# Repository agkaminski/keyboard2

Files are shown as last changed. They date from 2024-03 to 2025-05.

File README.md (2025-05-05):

# keyboard2

This repository contains designs of mechanical keyboards. Purpose of these
keyboards are custom DIY computers that are of all-in-keyboard design.

## keyboard69

This is a DIY 69% (nice) mechanical keyboard. Mostly to be used for DIY
computers, but there's a provision for USB/PS2 connection too.

Keyboard has been tested in the [FellaPC](https://github.com/agkaminski/FellaPC)
project and proven 100% functional. USB/PS2 connection has not been tested yet.

### Photos

#### Top



#### Bottom



## keyboard_mini

This is a reduced version of keyboard69 - rightmost column has been removed,
PCB size is as small, as possible. Provision for USB/PS2 has been removed.
Other connectors remain compatible with keyboard69.

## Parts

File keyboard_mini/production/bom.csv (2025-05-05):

Designator | Footprint | Quantity | Value | LCSC Part #
C1, C2 | 0805 | 2 | 100n
D1, D10, D11, D12, D13, D14, D16, D17, D18, D19, D2, D20, D21, D22, D23, D24, D25, D26, D27, D28, D29, D3, D31, D32, D33, D34, D35, D36, D37, D38, D39, D4, D40, D41, D42, D43, D45, D46, D47, D48, D49, D5, D50, D51, D52, D53, D54, D55, D56, D57, D59, D6, D60, D61, D62, D63, D64, D65, D66, D67, D7, D8, D9 | D_MiniMELF | 63 | D
J1 | IDC-Header_2x06_P2.54mm_Vertical | 1 | Conn_02x06_Odd_Even
J2 | PinSocket_1x12_P2.54mm_Vertical | 1 | Conn_01x12
J3 | TE_1-84952-2_1x12-1MP_P1.0mm_Horizontal | 1 | Conn_01x12_MountingPin
R10, R11, R12, R6, R8, R9 | 0805 | 6 | 10K
R7 | 0805 | 1 | DNP
SW1, SW10, SW11, SW12, SW13, SW17, SW18, SW19, SW2, SW20, SW21, SW22, SW23, SW24, SW25, SW26, SW27, SW28, SW3, SW32, SW33, SW34, SW35, SW36, SW37, SW38, SW39, SW4, SW40, SW41, SW42, SW46, SW47, SW48, SW49, SW5, SW50, SW51, SW52, SW53, SW54, SW55, SW57, SW6, SW63, SW64, SW65, SW66, SW67, SW7, SW8, SW9 | SW_Cherry_MX_1.00u_PCB | 52 | SW_Push
SW14 | SW_Cherry_MX_2.00u_PCB | 1 | SW_Push
SW16, SW29 | SW_Cherry_MX_1.50u_PCB | 2 | SW_Push
SW31, SW56 | SW_Cherry_MX_1.75u_PCB | 2 | SW_Push
SW43, SW45 | SW_Cherry_MX_2.25u_PCB | 2 | SW_Push
SW59, SW60, SW61 | SW_Cherry_MX_1.25u_PCB | 3 | SW_Push
SW62 | SW_Cherry_MX_6.25u_PCB | 1 | SW_Push
U1, U2 | SOIC-16_3.9x9.9mm_P1.27mm | 2 | 74HC138

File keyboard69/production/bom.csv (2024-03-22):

Designator | Footprint | Quantity | Value | LCSC Part #
C1, C2, C4, C7 | 0805 | 4 | 100n
C3 | 0805 | 1 | 1u
C5, C6 | 0805 | 2 | 22p
D1, D10, D11, D12, D13, D14, D15, D16, D17, D18, D19, D2, D20, D21, D22, D23, D24, D25, D26, D27, D28, D29, D3, D30, D31, D32, D33, D34, D35, D36, D37, D38, D39, D4, D40, D41, D42, D43, D44, D45, D46, D47, D48, D49, D5, D50, D51, D52, D53, D54, D55, D56, D57, D58, D59, D6, D60, D61, D62, D63, D64, D65, D66, D67, D68, D7, D8, D9 | D_MiniMELF | 68 | D
J1 | IDC-Header_2x06_P2.54mm_Vertical | 1 | Conn_02x06_Odd_Even
J2 | PinSocket_1x12_P2.54mm_Vertical | 1 | Conn_01x12
J3 | TE_1-84952-2_1x12-1MP_P1.0mm_Horizontal | 1 | Conn_01x12_MountingPin
J4 | USB_Mini-B_Wuerth_65100516121_Horizontal | 1 | USB_B_Mini
J5 | PinHeader_2x03_P2.54mm_Vertical | 1 | Conn_02x03_Odd_Even
R1, R2, R3, R4, R5, R6 | 0805 | 6 | 10K
R10 | 0805 | 1 | 4K7
R11, R12 | 0805 | 2 | 22R
R7 | 0805 | 1 | DNP
SW1, SW10, SW11, SW12, SW13, SW15, SW17, SW18, SW19, SW2, SW20, SW21, SW22, SW23, SW24, SW25, SW26, SW27, SW28, SW3, SW30, SW32, SW33, SW34, SW35, SW36, SW37, SW38, SW39, SW4, SW40, SW41, SW42, SW44, SW46, SW47, SW48, SW49, SW5, SW50, SW51, SW52, SW53, SW54, SW55, SW57, SW58, SW6, SW63, SW64, SW65, SW66, SW67, SW68, SW7, SW8, SW9 | SW_Cherry_MX_1.00u_PCB | 57 | SW_Push
SW14 | SW_Cherry_MX_2.00u_PCB | 1 | SW_Push
SW16, SW29 | SW_Cherry_MX_1.50u_PCB | 2 | SW_Push
SW31, SW56 | SW_Cherry_MX_1.75u_PCB | 2 | SW_Push
SW43, SW45 | SW_Cherry_MX_2.25u_PCB | 2 | SW_Push
SW59, SW60, SW61 | SW_Cherry_MX_1.25u_PCB | 3 | SW_Push
SW62 | SW_Cherry_MX_6.25u_PCB | 1 | SW_Push
U1, U2 | SOIC-16_3.9x9.9mm_P1.27mm | 2 | 74HC138
U3 | TQFP-44_10x10mm_P0.8mm | 1 | ATmega16U4-A
Y1 | Crystal_HC49-4H_Vertical | 1 | Crystal

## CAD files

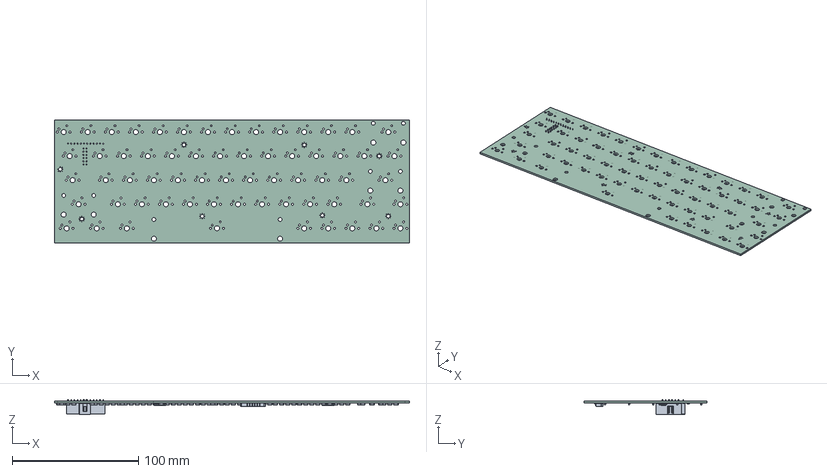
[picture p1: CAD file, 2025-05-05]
keyboard_mini/keyboard2.step
281.2 x 97.0 x 12.2 mm
D_MiniMELF x 63
PinSocket_1x12_P2.54mm_Vertical
R_0805_2012Metric x 7
SOIC-16_3.9x9.9mm_P1.27mm x 2
IDC-Header_2x06_P2.54mm_Vertical
C_0805_2012Metric x 2
TE_1-84952-2_1x12-1MP_P1.0mm_Horizontal
keyboard2_PCB

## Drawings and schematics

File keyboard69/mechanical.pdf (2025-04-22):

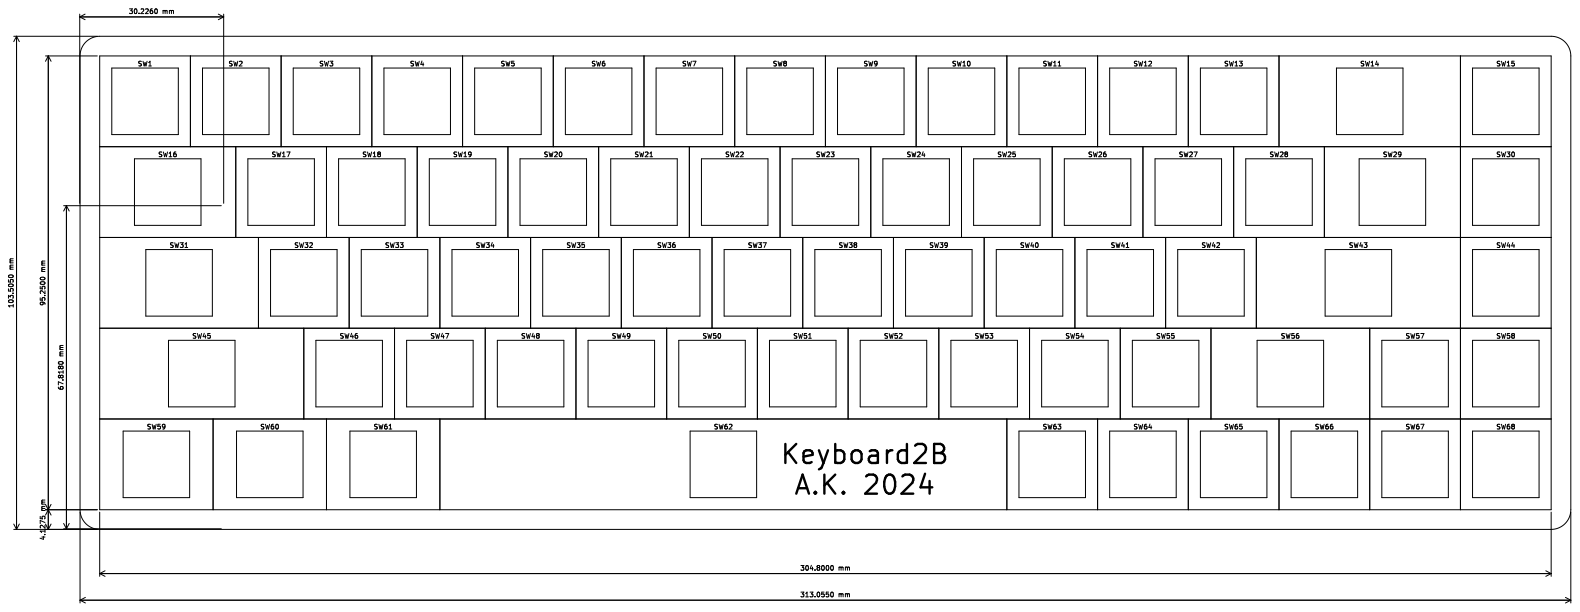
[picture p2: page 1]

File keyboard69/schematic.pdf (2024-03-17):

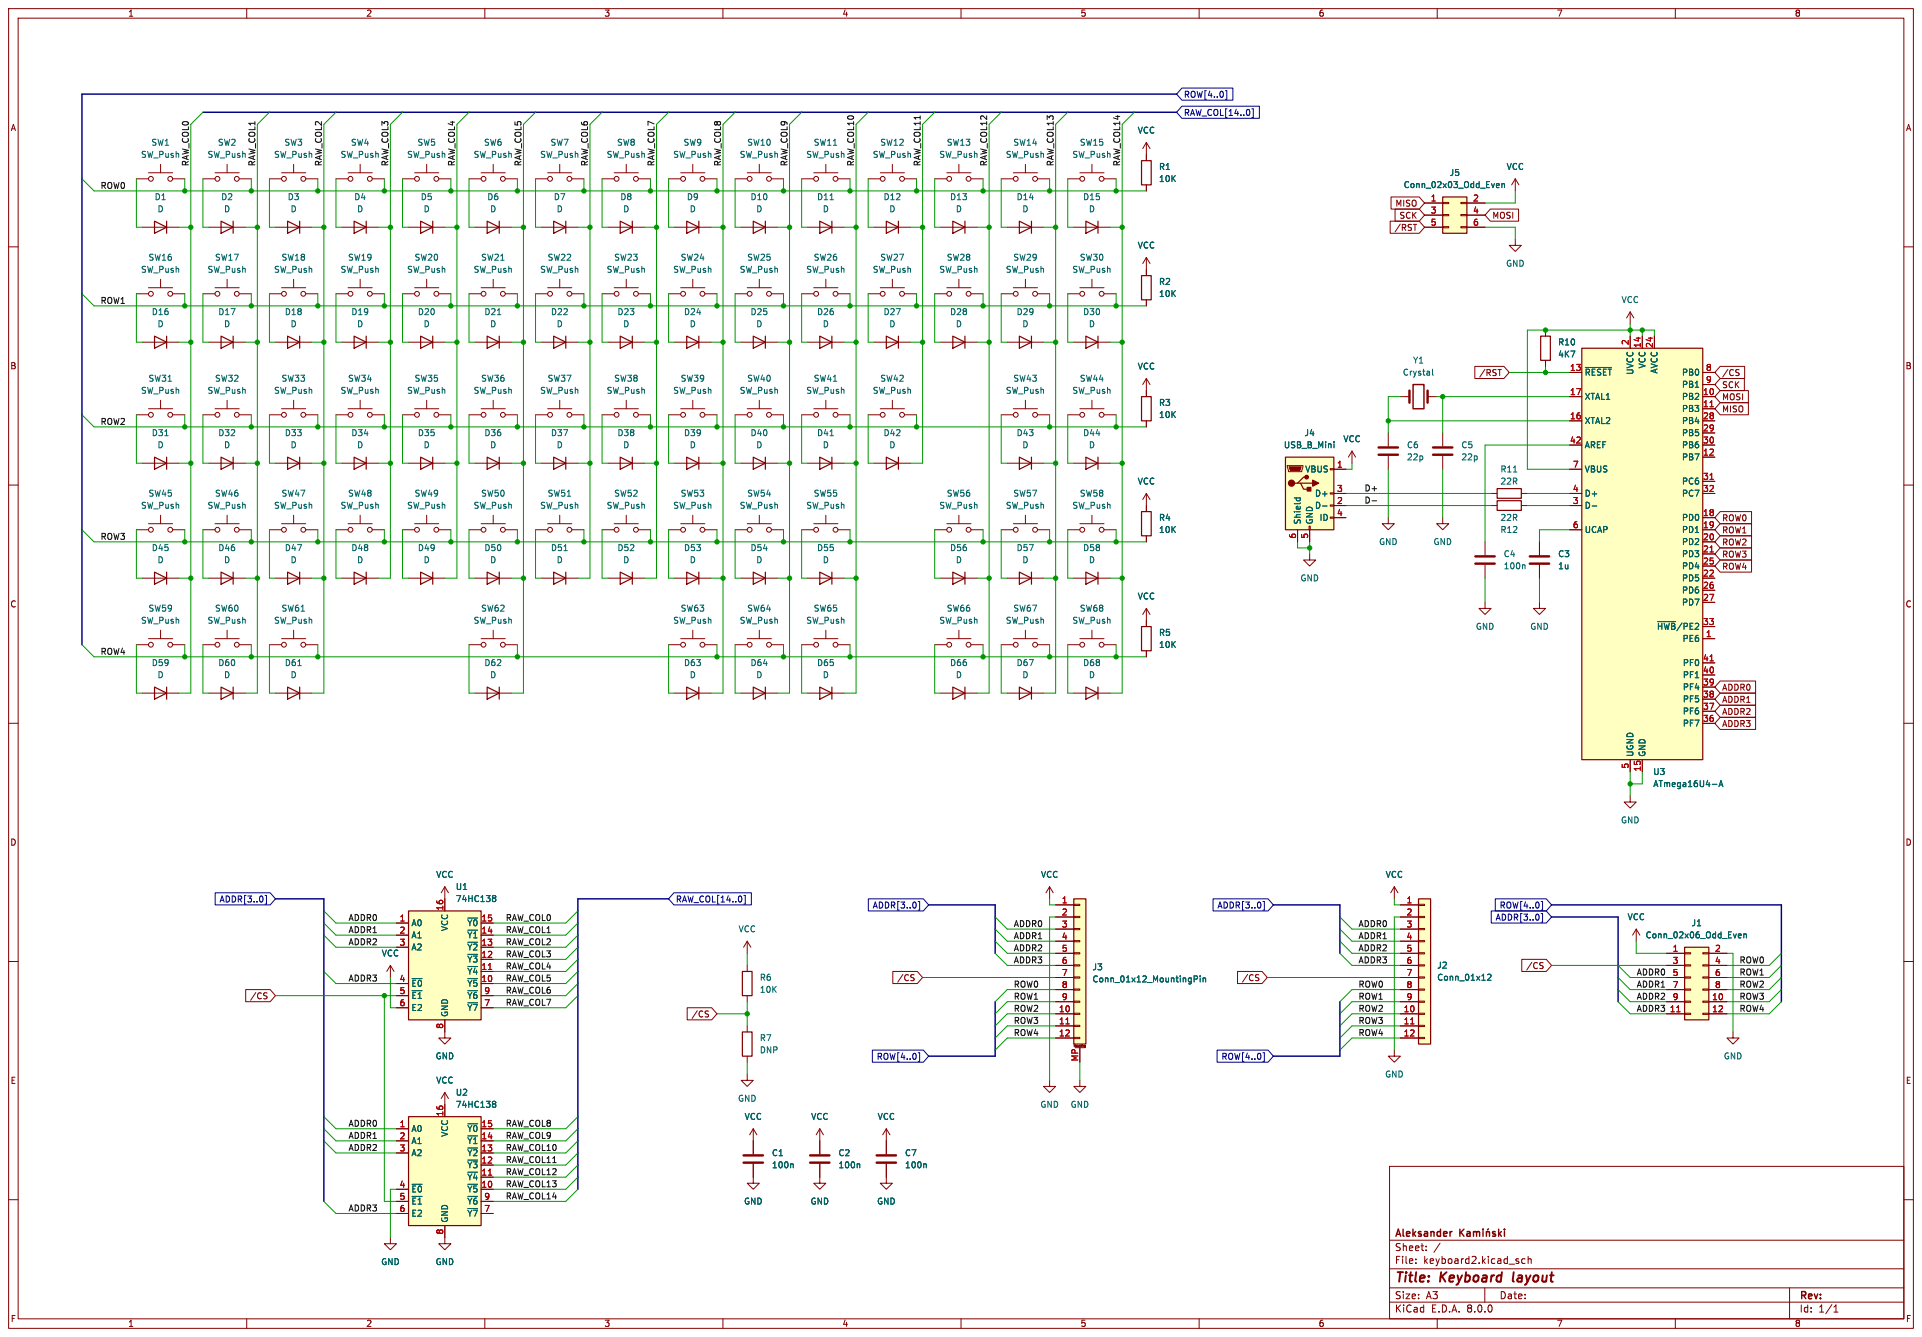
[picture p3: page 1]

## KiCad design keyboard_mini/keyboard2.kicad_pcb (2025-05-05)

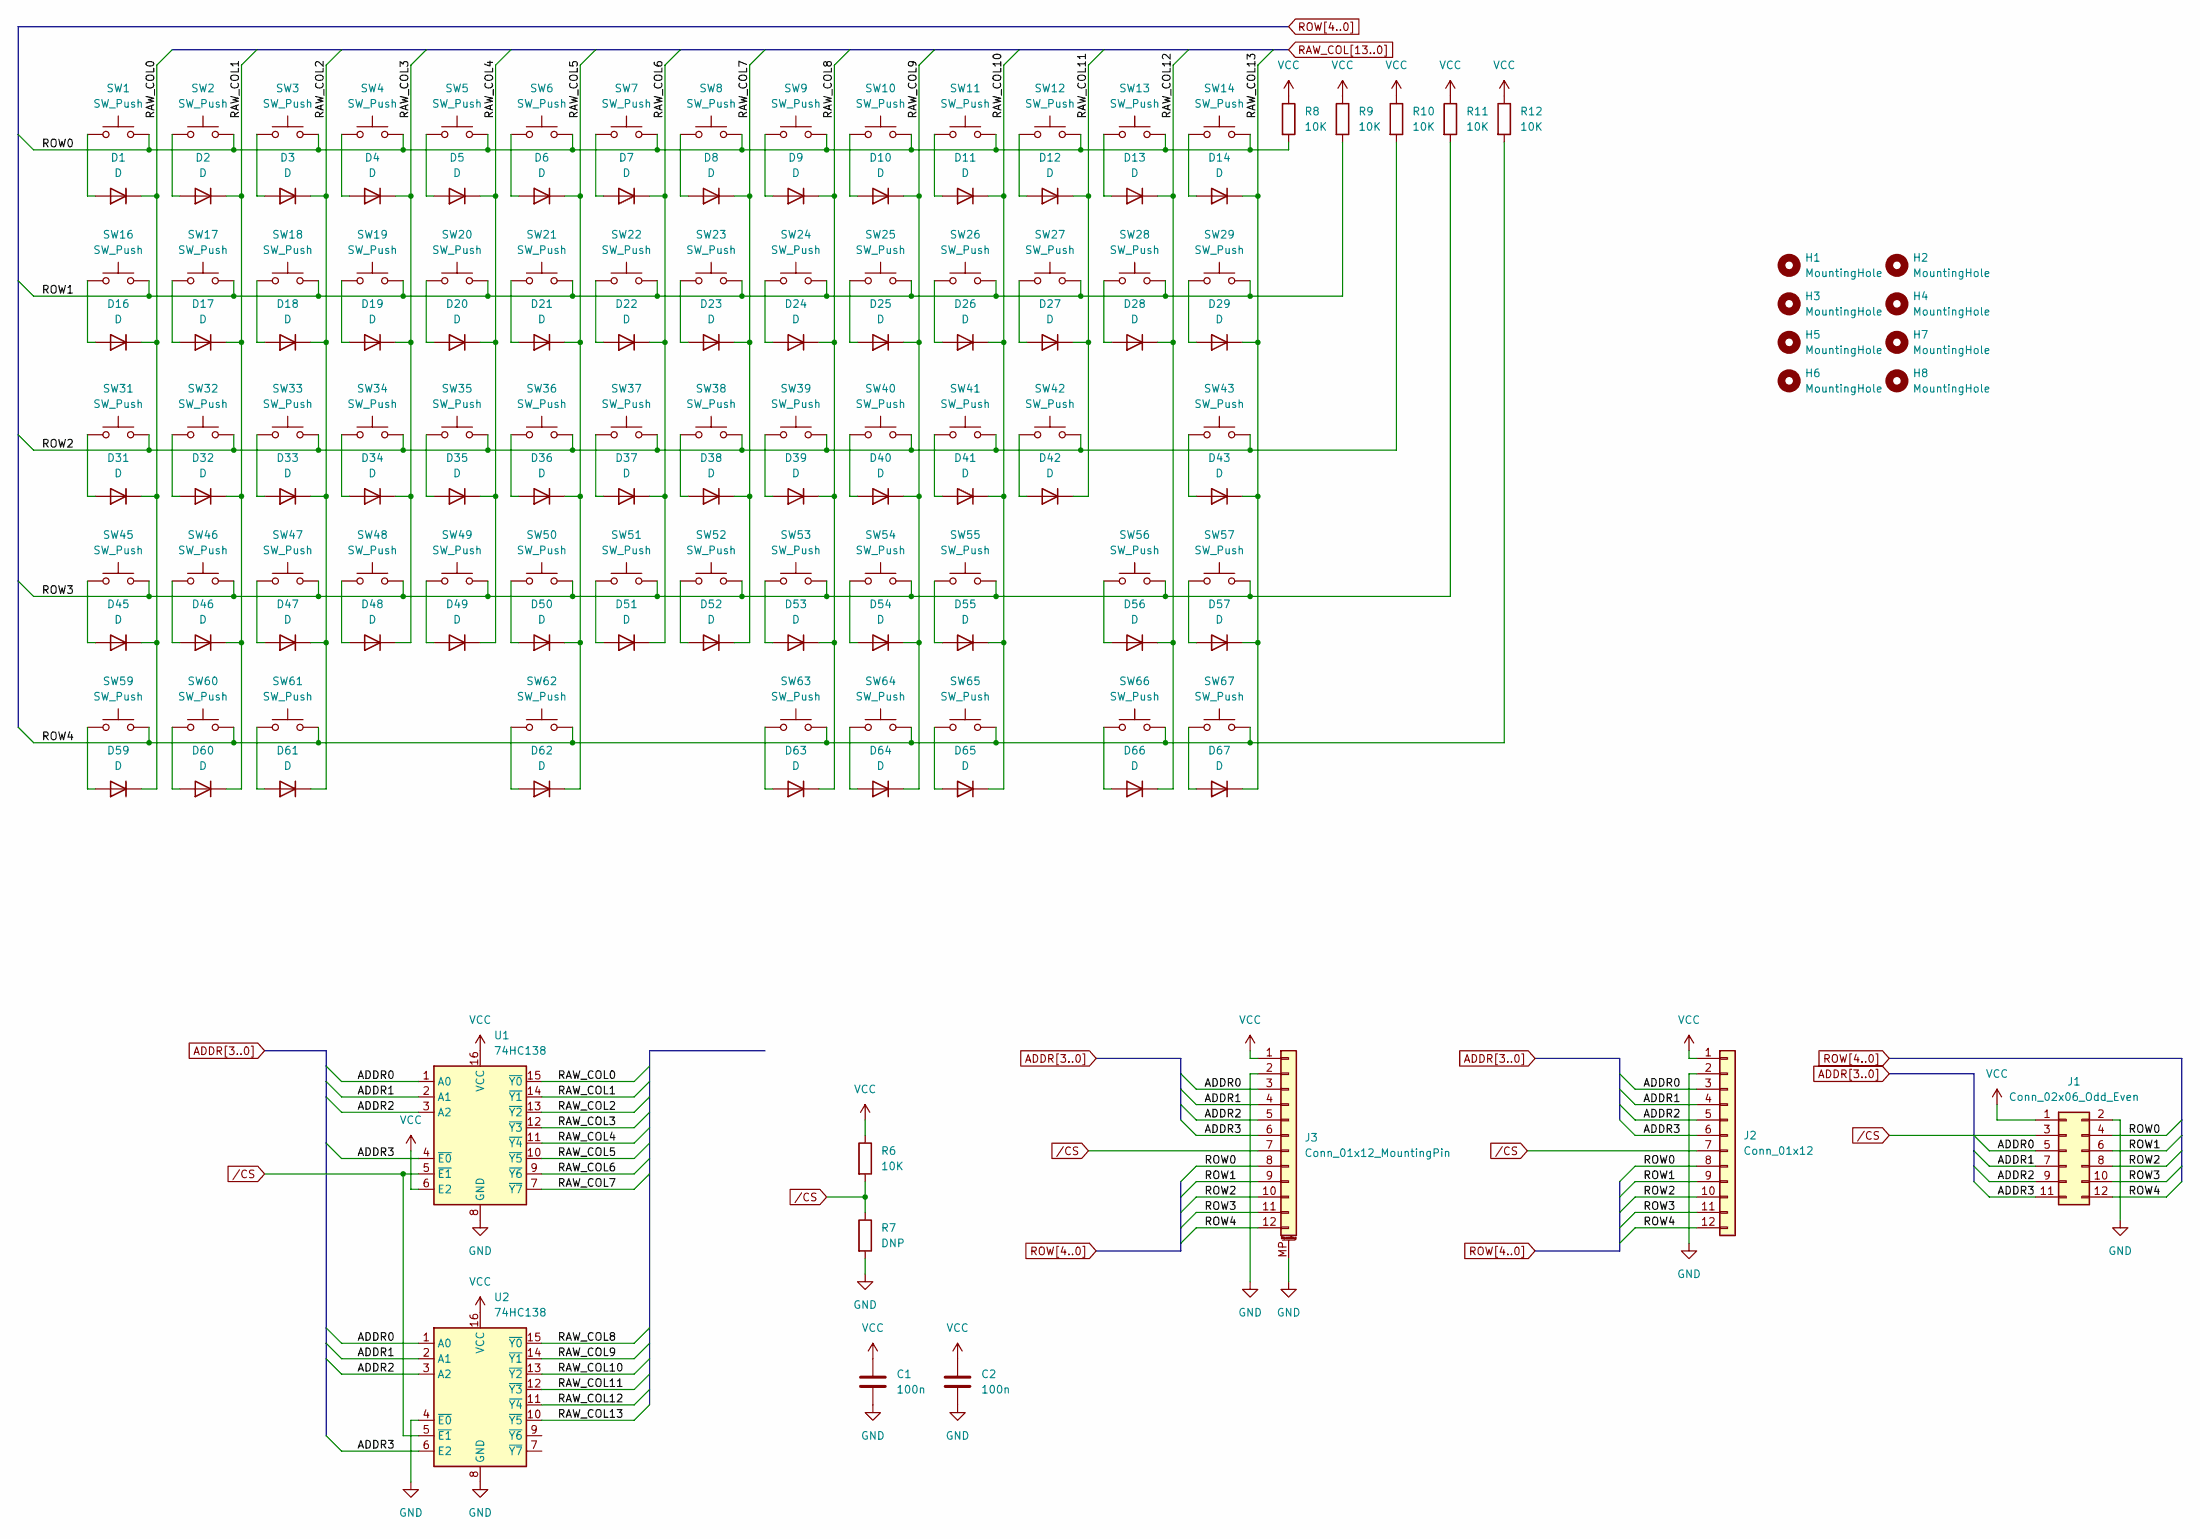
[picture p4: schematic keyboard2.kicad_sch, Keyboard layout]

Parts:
C1, C2: 100n; C_0805_2012Metric_Pad1.18x1.45mm_HandSolder
D1, D2, D3, D4, D5, D6, D7, D8, D9, D10, D11, D12, D13, D14, D16, D17, D18, D19, D20, D21, D22, D23, D24, D25, D26, D27, D28, D29, D31, D32, D33, D34, D35, D36, D37, D38, D39, D40, D41, D42, D43, D45, D46, D47, D48, D49, D50, D51, D52, D53, D54, D55, D56, D57, D59, D60, D61, D62, D63, D64, D65, D66, D67: D; D_MiniMELF
H1, H2, H3, H4, H5, H6, H7, H8: MountingHole; MountingHole_2.7mm_M2.5_Pad_Via
J1: Conn_02x06_Odd_Even; IDC-Header_2x06_P2.54mm_Vertical
J2: Conn_01x12; PinSocket_1x12_P2.54mm_Vertical
J3: Conn_01x12_MountingPin; TE_1-84952-2_1x12-1MP_P1.0mm_Horizontal
R6, R8, R9, R10, R11, R12: 10K; R_0805_2012Metric_Pad1.20x1.40mm_HandSolder
R7: DNP; R_0805_2012Metric_Pad1.20x1.40mm_HandSolder
SW1, SW2, SW3, SW4, SW5, SW6, SW7, SW8, SW9, SW10, SW11, SW12, SW13, SW17, SW18, SW19, SW20, SW21, SW22, SW23, SW24, SW25, SW26, SW27, SW28, SW32, SW33, SW34, SW35, SW36, SW37, SW38, SW39, SW40, SW41, SW42, SW46, SW47, SW48, SW49, SW50, SW51, SW52, SW53, SW54, SW55, SW57, SW63, SW64, SW65, SW66, SW67: SW_Push; SW_Cherry_MX_1.00u_PCB
SW14: SW_Push; SW_Cherry_MX_2.00u_PCB
SW16, SW29: SW_Push; SW_Cherry_MX_1.50u_PCB
SW31, SW56: SW_Push; SW_Cherry_MX_1.75u_PCB
SW43, SW45: SW_Push; SW_Cherry_MX_2.25u_PCB
SW59, SW60, SW61: SW_Push; SW_Cherry_MX_1.25u_PCB
SW62: SW_Push; SW_Cherry_MX_6.25u_PCB
U1, U2: 74HC138; SOIC-16_3.9x9.9mm_P1.27mm

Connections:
ADDR0: J1.5, J2.3, J3.3, U1.1 (A0), U2.1 (A0)
ADDR1: J1.7, J2.4, J3.4, U1.2 (A1), U2.2 (A1)
ADDR2: J1.9, J2.5, J3.5, U1.3 (A2), U2.3 (A2)
ADDR3: J1.11, J2.6, J3.6, U1.4 (~E0), U2.6 (E2)
GND: C1.2, C2.2, J1.2, J2.2, J3.2, J3.MP (MountPin), R7.2, U1.8 (GND), U2.4 (~E0), U2.8 (GND)
unnamed: D1.2 (A), SW1.1
unnamed: D2.2 (A), SW2.1
unnamed: D3.2 (A), SW3.1
unnamed: D4.2 (A), SW4.1
unnamed: D5.2 (A), SW5.1
unnamed: D6.2 (A), SW6.1
unnamed: D7.2 (A), SW7.1
unnamed: D8.2 (A), SW8.1
unnamed: D9.2 (A), SW9.1
unnamed: D10.2 (A), SW10.1
unnamed: D11.2 (A), SW11.1
unnamed: D12.2 (A), SW12.1
unnamed: D13.2 (A), SW13.1
unnamed: D14.2 (A), SW14.1
unnamed: D16.2 (A), SW16.1
unnamed: D17.2 (A), SW17.1
unnamed: D18.2 (A), SW18.1
unnamed: D19.2 (A), SW19.1
unnamed: D20.2 (A), SW20.1
unnamed: D21.2 (A), SW21.1
unnamed: D22.2 (A), SW22.1
unnamed: D23.2 (A), SW23.1
unnamed: D24.2 (A), SW24.1
unnamed: D25.2 (A), SW25.1
unnamed: D26.2 (A), SW26.1
unnamed: D27.2 (A), SW27.1
unnamed: D28.2 (A), SW28.1
unnamed: D29.2 (A), SW29.1
unnamed: D31.2 (A), SW31.1
unnamed: D32.2 (A), SW32.1
unnamed: D33.2 (A), SW33.1
unnamed: D34.2 (A), SW34.1
unnamed: D35.2 (A), SW35.1
unnamed: D36.2 (A), SW36.1
unnamed: D37.2 (A), SW37.1
unnamed: D38.2 (A), SW38.1
unnamed: D39.2 (A), SW39.1
unnamed: D40.2 (A), SW40.1
unnamed: D41.2 (A), SW41.1
unnamed: D42.2 (A), SW42.1
unnamed: D43.2 (A), SW43.1
unnamed: D45.2 (A), SW45.1
unnamed: D46.2 (A), SW46.1
unnamed: D47.2 (A), SW47.1
unnamed: D48.2 (A), SW48.1
unnamed: D49.2 (A), SW49.1
unnamed: D50.2 (A), SW50.1
unnamed: D51.2 (A), SW51.1
unnamed: D52.2 (A), SW52.1
unnamed: D53.2 (A), SW53.1
unnamed: D54.2 (A), SW54.1
unnamed: D55.2 (A), SW55.1
unnamed: D56.2 (A), SW56.1
unnamed: D57.2 (A), SW57.1
unnamed: D59.2 (A), SW59.1
unnamed: D60.2 (A), SW60.1
unnamed: D61.2 (A), SW61.1
unnamed: D62.2 (A), SW62.1
unnamed: D63.2 (A), SW63.1
unnamed: D64.2 (A), SW64.1
unnamed: D65.2 (A), SW65.1
unnamed: D66.2 (A), SW66.1
unnamed: D67.2 (A), SW67.1
RAW_COL0: D1.1 (K), D16.1 (K), D31.1 (K), D45.1 (K), D59.1 (K), U1.15 (~Y0)
RAW_COL1: D2.1 (K), D17.1 (K), D32.1 (K), D46.1 (K), D60.1 (K), U1.14 (~Y1)
RAW_COL2: D3.1 (K), D18.1 (K), D33.1 (K), D47.1 (K), D61.1 (K), U1.13 (~Y2)
RAW_COL3: D4.1 (K), D19.1 (K), D34.1 (K), D48.1 (K), U1.12 (~Y3)
RAW_COL4: D5.1 (K), D20.1 (K), D35.1 (K), D49.1 (K), U1.11 (~Y4)
RAW_COL5: D6.1 (K), D21.1 (K), D36.1 (K), D50.1 (K), D62.1 (K), U1.10 (~Y5)
RAW_COL6: D7.1 (K), D22.1 (K), D37.1 (K), D51.1 (K), U1.9 (~Y6)
RAW_COL7: D8.1 (K), D23.1 (K), D38.1 (K), D52.1 (K), U1.7 (~Y7)
RAW_COL8: D9.1 (K), D24.1 (K), D39.1 (K), D53.1 (K), D63.1 (K), U2.15 (~Y0)
RAW_COL9: D10.1 (K), D25.1 (K), D40.1 (K), D54.1 (K), D64.1 (K), U2.14 (~Y1)
RAW_COL10: D11.1 (K), D26.1 (K), D41.1 (K), D55.1 (K), D65.1 (K), U2.13 (~Y2)
RAW_COL11: D12.1 (K), D27.1 (K), D42.1 (K), U2.12 (~Y3)
RAW_COL12: D13.1 (K), D28.1 (K), D56.1 (K), D66.1 (K), U2.11 (~Y4)
RAW_COL13: D14.1 (K), D29.1 (K), D43.1 (K), D57.1 (K), D67.1 (K), U2.10 (~Y5)
ROW0: J1.4, J2.8, J3.8, R8.2, SW1.2, SW2.2, SW3.2, SW4.2, SW5.2, SW6.2, SW7.2, SW8.2, SW9.2, SW10.2, SW11.2, SW12.2, SW13.2, SW14.2
ROW1: J1.6, J2.9, J3.9, R9.2, SW16.2, SW17.2, SW18.2, SW19.2, SW20.2, SW21.2, SW22.2, SW23.2, SW24.2, SW25.2, SW26.2, SW27.2, SW28.2, SW29.2
ROW2: J1.8, J2.10, J3.10, R10.2, SW31.2, SW32.2, SW33.2, SW34.2, SW35.2, SW36.2, SW37.2, SW38.2, SW39.2, SW40.2, SW41.2, SW42.2, SW43.2
ROW3: J1.10, J2.11, J3.11, R11.2, SW45.2, SW46.2, SW47.2, SW48.2, SW49.2, SW50.2, SW51.2, SW52.2, SW53.2, SW54.2, SW55.2, SW56.2, SW57.2
ROW4: J1.12, J2.12, J3.12, R12.2, SW59.2, SW60.2, SW61.2, SW62.2, SW63.2, SW64.2, SW65.2, SW66.2, SW67.2
VCC: C1.1, C2.1, J1.1, J2.1, J3.1, R6.1, R8.1, R9.1, R10.1, R11.1, R12.1, U1.6 (E2), U1.16 (VCC), U2.16 (VCC)
/CS: J1.3, J2.7, J3.7, R6.2, R7.1, U1.5 (~E1), U2.5 (~E1)

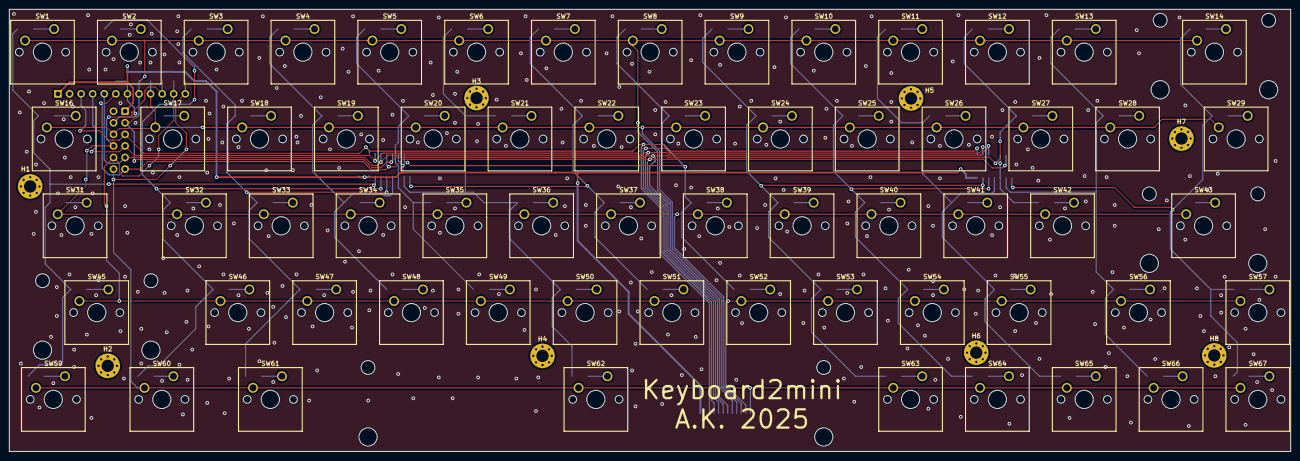
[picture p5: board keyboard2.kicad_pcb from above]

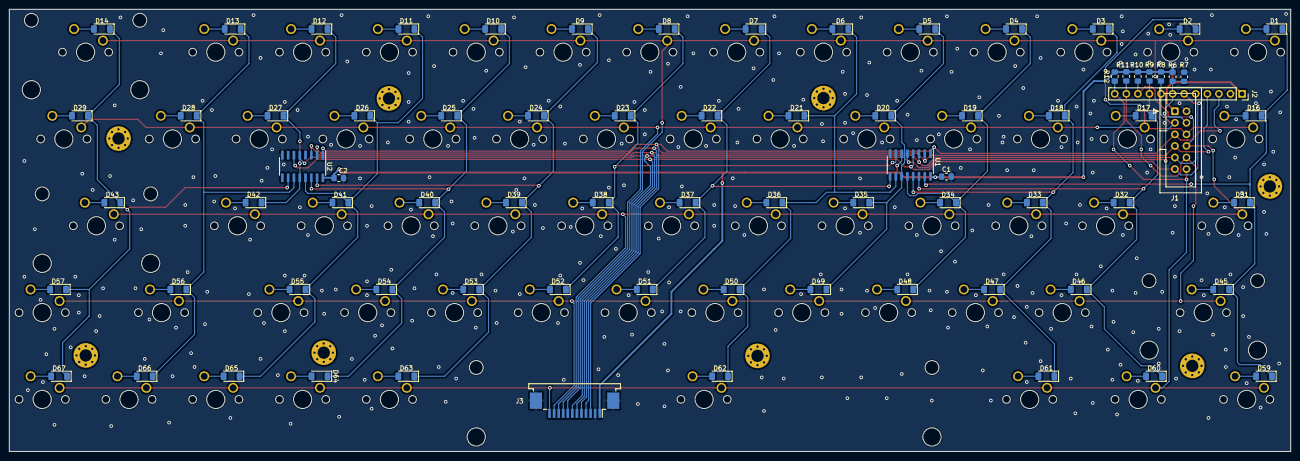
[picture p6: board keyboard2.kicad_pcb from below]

Board: 2 copper layers, 281.2 x 97.0 mm, 148 parts (77 on the bottom side), 89 nets.

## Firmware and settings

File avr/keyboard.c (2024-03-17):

#include <avr/io.h>
#include <avr/pgmspace.h>
#include <avr/cpufunc.h>

#include <stdint.h>

#include "keyboard.h"
#include "keys.h"

#define K(main, alt) (((alt) << 8) | ((main) & 0xff))
#define MAIN(key) ((key) & 0xff)
#define ALT(key) (((key) >> 8) & 0xff) 

static uint8_t lastState[16];


static uint16_t keyMap(int row, int col)
{
	static const uint16_t map[5][16] PROGMEM = {
	{
		K(KEY_ESC, KEY_GRAVE), K(KEY_1, KEY_F1), K(KEY_2, KEY_F2),
		K(KEY_3, KEY_F3), K(KEY_4, KEY_F4), K(KEY_5, KEY_F5), K(KEY_6, KEY_F6),
		K(KEY_7, KEY_F7), K(KEY_8, KEY_F8), K(KEY_9, KEY_F0), K(KEY_0, KEY_F10),
		K(KEY_MINUS, KEY_F11), K(KEY_EQUAL, KEY_F12),
		K(KEY_BACKSPACE, KEY_BACKSPACE), K(KEY_DELETE, KEY_DELETE)
	},
	{
		K(KEY_TAB, KEY_TAB), K(KEY_Q, KEY_Q), K(KEY_W, KEY_W), K(KEY_E, KEY_E),
		K(KEY_R, KEY_R), K(KEY_T, KEY_T), K(KEY_Y, KEY_Y), K(KEY_U, KEY_U),
		K(KEY_I, KEY_I), K(KEY_O, KEY_O), K(KEY_P, KEY_P),
		K(KEY_LEFTBRACE, KEY_LEFTBRACE), K(KEY_RIGHTBRACE, KEY_RIGHTBRACE),
		K(KEY_BACKSLASH, KEY_BACKSLASH), K(KEY_PAGEUP, KEY_PAGEUP)
	},
	{
		K(KEY_CAPSLOCK, KEY_CAPSLOCK), K(KEY_A, KEY_A), K(KEY_S, KEY_S),
		K(KEY_D, KEY_D), K(KEY_F, KEY_F), K(KEY_G, KEY_G), K(KEY_H, KEY_H),
		K(KEY_J, KEY_J), K(KEY_K, KEY_K), K(KEY_L, KEY_L),
		K(KEY_SEMICOLON, KEY_SEMICOLON), K(KEY_APOSTROPHE, KEY_APOSTROPHE),
		K(KEY_NONE, KEY_NONE), K(KEY_ENTER, KEY_ENTER),
		K(KEY_PAGEDOWN, KEY_PAGEDOWN)
	},
	{
		K(KEY_LEFTSHIFT, KEY_LEFTSHIFT), K(KEY_Z, KEY_Z), K(KEY_X, KEY_X),
		K(KEY_C, KEY_C), K(KEY_V, KEY_V), K(KEY_B, KEY_B), K(KEY_N, KEY_N),
		K(KEY_M, KEY_M), K(KEY_COMMA, KEY_COMMA), K(KEY_DOT, KEY_DOT),
		K(KEY_NONE, KEY_NONE), K(KEY_RIGHTSHIFT, KEY_RIGHTSHIFT),
		K(KEY_UP, KEY_MEDIA_VOLUMEUP), K(KEY_HOME, KEY_END)
	},
	{
		K(KEY_LEFTCTRL, KEY_LEFTCTRL), K(KEY_LEFTMETA, KEY_LEFTMETA),
		K(KEY_LEFTALT, KEY_LEFTALT), K(KEY_NONE, KEY_NONE),
		K(KEY_NONE, KEY_NONE), K(KEY_SPACE, KEY_MEDIA_PLAYPAUSE),
		K(KEY_NONE, KEY_NONE), K(KEY_NONE, KEY_NONE),
		K(KEY_RIGHTALT, KEY_RIGHTALT), K(KEY_NONE, KEY_NONE),
		K(KEY_RIGHTCTRL, KEY_RIGHTCTRL), K(KEY_FN, KEY_FN),
		K(KEY_LEFT, KEY_MEDIA_BACK), K(KEY_DOWN, KEY_MEDIA_VOLUMEDOWN),
		K(KEY_RIGHT, KEY_MEDIA_FORWARD)
	} };

	return pgm_read_word(&map[row][col]);
}

static int isModifier(uint8_t key)
{
	switch (key) {
		case KEY_LEFTSHIFT:
		case KEY_RIGHTSHIFT:
		case KEY_LEFTCTRL:
		case KEY_LEFTALT:
		case KEY_RIGHTALT:
		case KEY_RIGHTCTRL:
		case KEY_FN:
			return 1;
		default:
			return 0;
	}
}

static int keyPress(struct keys *keys, uint8_t key)
{
	/* Find first free place */
	for (size_t i = 0; i < sizeof(keys->keys) / sizeof(keys->keys[0]); ++i) {
		if (keys->keys[i] == KEY_NONE) {
			keys->keys[i] = key;
			return 0;
		}
	}
	
	/* Overflow */
	return -1;
}

static int keyRelease(struct keys *keys, uint8_t key)
{
	for (size_t i = 0; i < sizeof(keys->keys) / sizeof(keys->keys[0]); ++i) {
		if (keys->keys[i] == key) {
			/* Remove and compress */
			for (; i < sizeof(keys->keys) / sizeof(keys->keys[0]) - 1; ++i) {
				keys->keys[i] = keys->keys[i + 1];
			}
			
			keys->keys[i] = KEY_NONE;
			
			return 0;
		}
	}
	
	/* Key not found? */
	return -1;
}

static uint8_t scanRow(int col)
{
	uint8_t t = PORTF & ~0xf0;
	PORTF = t | ((col & 0xf) << 4);
	nop();
	return PIND & 0x1f;
}

int keyboard_update(struct keys *keys)
{
	for (size_t i = 0; i < sizeof(lastState) / sizeof(*lastState); ++i) {
		uint8_t row = scanRow(i);
		
		/* Find keys that changed */
		uint8_t change = row ^ lastState[i];
		
		for (size_t j = 0; change != 0; ++j) {
			if (change & 1) {
			
			}
		}
	}
}


void keyboard_init(void)
{
	/* Row input */
	DDRD &= ~0x1f;
	
	/* Col select */
	DDRF = 0xf0;
	
	/* Just enable /CS */
	DDRB |= 1;
	PORTB &= ~1;
}

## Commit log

2024-03-17 Initial import
    [bom.csv, designators.csv, keyboard2.kicad_pcb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]
2024-03-22 Revision B:
    - fix wrong space size (6.5u -> 6.25u),
    - fix wrong right shift size (2u -> 1.75u),
    - fix wrong placement of space stabilizer,
    - fix J1 being mirrored against IDC-12 connector,
    - change diodes footprint (hand soldering version has way too big pads),
    - reroute.
    [bom.csv, designators.csv, keyboard2.kicad_pcb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]
2025-05-05 Add keyboard2 mini
    [bom.csv, designators.csv, keyboard2.kicad_pcb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]
2025-05-05 mini: add step model
    [keyboard2.step]
